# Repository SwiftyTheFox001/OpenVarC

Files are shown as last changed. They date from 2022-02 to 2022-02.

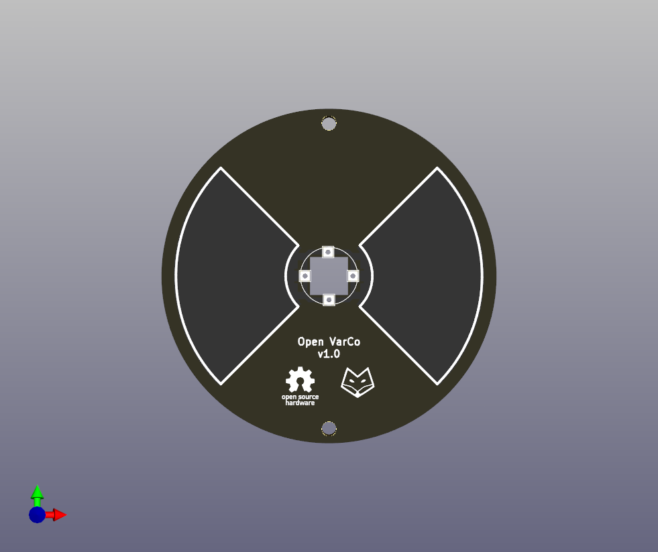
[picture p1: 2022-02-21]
Images/openVarC_large_Rotor.png

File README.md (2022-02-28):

# OpenVarC
OSHW Variable Capacitor based on PCBs

This project intends to find a viable alternative for the variable capacitors for high voltages that got rare in modern electronics, but are still in demand for ham radio operators for various projects. At the moment this project is still in "beta phase" covers only one size of cap and some specs are still to be tested like the max. AC voltage capability. Please consider this while rebuilding a capacitor.

Features:
- Modular
- Uses PCBs and easily available mechanic parts (metric screws, washers & nuts)
- at least 2kV 
- Holes for light barrier to allow automatic centering

Future development:
- different sizes
- measuring max. Voltage capability
- optimizing the center tapped 

On ordering the PCBs:
- Thickness: 0.8mm
- Amount of PCBs: use calculations.ods to calculate the approximate amount of needed stacks and order a bit more. The amount depends on the dielectric properties of the used FR4 material. Milage may vary!

What you need for the large VarCs:
- Stator plate PCBs
- Rotor plate PCBs
- 4x M4 threaded rods of the same length
- 16x M4 Nuts
- M4 Washers (4 between 2 stators)
- 8mm rectangular aluminium extrusion (Axis) Note: Can be a U-shaped extrusion as well
- Cable shoes that fit on the M4 threaded rod
- 3D printed parts:
  - 2x H750.stl
  - 1x H751_1.stl
  - 1x H751_2.stl
- a Saw 

Assembly:
1) Lengthen the rectrangular axis and the 4 threaded rods depending on your need. Calculate some extra length to ensure that you can add a few stacks later if needed
2) put one M4 Nut min. 1cm from the ends of each threaded rod
3) Stack the PCBs the following way:
- Slide stator plate with silk screen showing upside (text/markings) on the four threaded rods
- First stack: put the axis inside the circular center hole of the stator plate
- Slide rotor plate with silk screen showing upside (text/markings) on the Axis
- Slide one washer on each of the threaded rods
- repeat the process with sliding a stator plate on top and ensure that the light barrier hole is aligned with the bottom layers
4) finishing the assembly
- ensure that all outside plates are stator plates
- put 4 M4 Nuts on top of thestack and tighten them carefully
- put the 3D printed parts 751_1 and 751_2 on both ends of the axis. Move the axis so, that the part 751_2 (endcap that prevents axis from going throuh) lies flush with the stator plate
- slide the two 3D printed parts 750 on the ends of the caps. Ensure that the light barrier holes are aligned
- slide the cable shoes on the threaded rods
- tighten with with M4 nuts

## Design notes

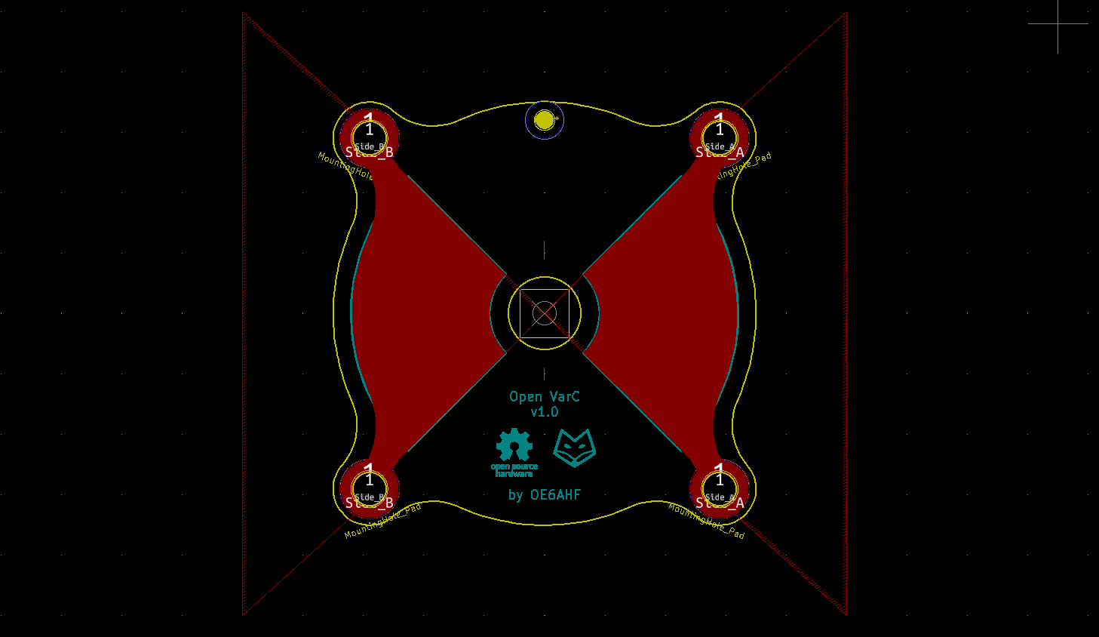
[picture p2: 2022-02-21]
Images/openVarC_large_Stator.png

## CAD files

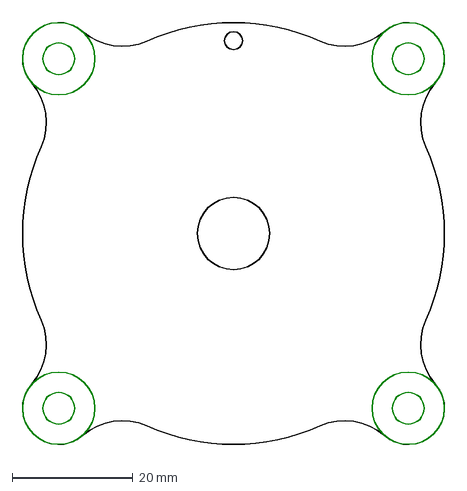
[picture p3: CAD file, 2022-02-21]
3D Files/#openVarC_large.dxf
72.1 x 72.1 mm

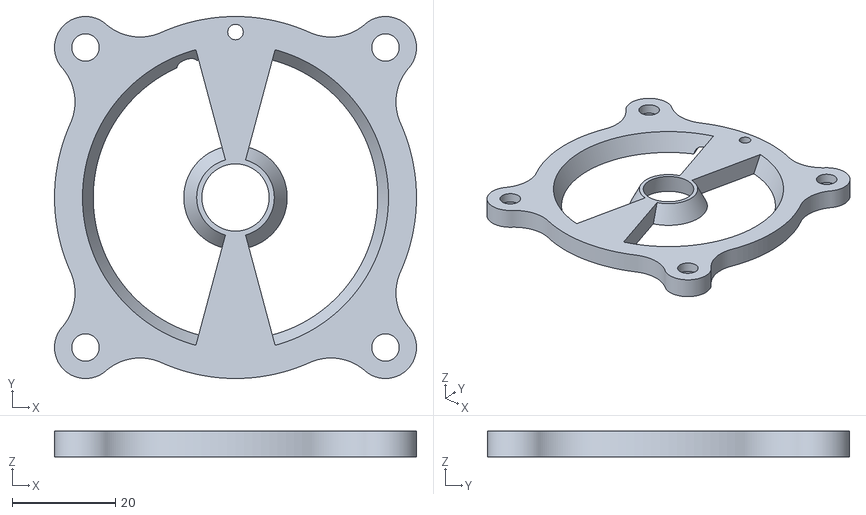
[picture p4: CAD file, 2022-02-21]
3D Files/STL/H750.stl
70.0 x 70.0 x 5.00

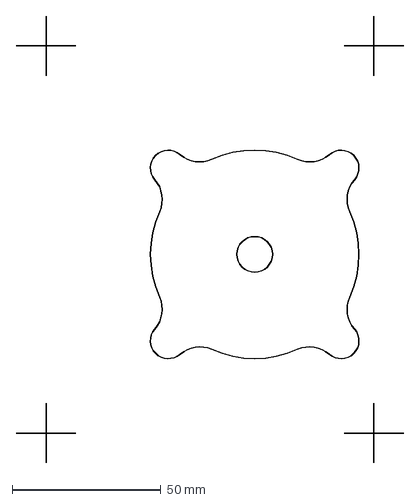
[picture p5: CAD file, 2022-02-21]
VarCo_large/openVarC_large.dxf
130.0 x 150.0 mm

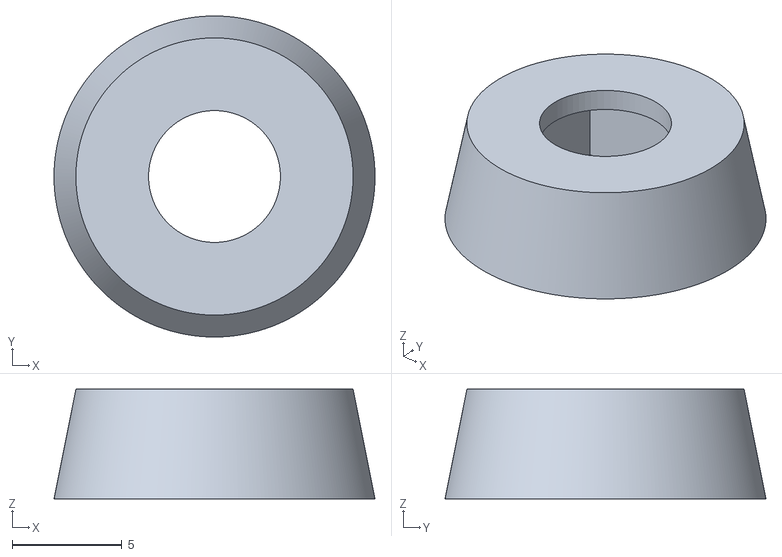
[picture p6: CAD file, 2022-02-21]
3D Files/STL/H751_2.stl
14.6 x 14.6 x 5.00

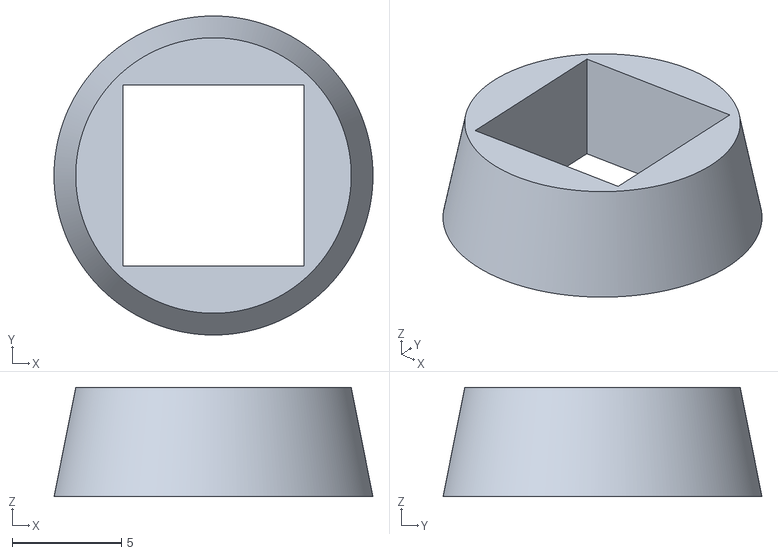
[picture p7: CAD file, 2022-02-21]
3D Files/STL/H751_1.stl
14.6 x 14.6 x 5.00

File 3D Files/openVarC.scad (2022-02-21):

//OpenVarc - 3D Files and Assembly
//
//by OE6AHF & OE6MDW
//relesed under the CC-BY-SA 4.0

use_stls = true;
LOD=128;

include <openVarC_parts.scad>



//
// Printable PARTS
//

*H750();		//Top Plate
*H751_1();		//Alignment Disk Open
*H751_2();		//Alignment Disk Endcap

//
// ASSEMBLY
//

assembly();

	
module assembly()
    {
    translate([0,0,5+0+6+pcbStacks*(2*pcbHeight+2*pcbSpace)+pcbHeight])
        {
        H750(); // Top Plate
        H751_2(); // Alignment Disk       
        }
    translate([0,0,11])
		rotate([0,180,0])
        {
        H750(); // Top Plate
        H751_1(); // Alignment Disk       
        }
              
    // VarCo
	translate([0,0,5+0+6])
		P100();
	
    }
    
//
//  PARTS
//

//
// H750 - Top Plate
//

module H750()
    {
    if (use_stls)
        {
        color("orange")
            import("./STL/H750.stl");
        }
    else
        {
        color("darkorange")
        difference()
            {
            union()
                {
                    
                // Outer Ring
                difference()
                    {
                    union()
                        {
                        linear_extrude(height=5)
                            import($fn=128, "openVarC_large.dxf", "Stator");
                        }
                    translate([0,0,-0.01])
                        cylinder($fn=LOD*2, r2=60/2, r1=55/2, h=6);
                    
                    for (i=[0:3])
                        {
                        rotate([0,0,90*i])
                            translate([29,29,-0.5])
                            cylinder($fn=64, r=9.1/2, h=3.05);
                        }
                        
                    }
                //Inner Ring
                translate([0,0,0])
                    cylinder($fn=LOD*2, r2=15/2, r1=20/2, h=5);               
                
                //Bars
                linear_extrude(height=5)
                    polygon(points=[
                        [31*cos(75),31*sin(75)],
                        [31*cos(105),31*sin(105)],

                        [5*cos(105),5*sin(105)],
                        [5*cos(-105),5*sin(-105)],

                        [31*cos(-105),31*sin(-105)],
                        [31*cos(-75),31*sin(-75)],       
       
                        [5*cos(-75),5*sin(-75)],
                        [5*cos(75),5*sin(75)],                    
                        ]);
                    
                }
            translate([0,0,-0.01])
                cylinder($fn=LOD*2, r1=15/2, r2=13/2, h=5.02);          
                         
            rotate([0,0,20])
                translate([0,25,0])
                rotate([-90,0,0])
                cylinder($fn=32,r=2, h=50);
                
                

            }
        }        
    }

//
// H751 - Alignment Disk
//

module H751_1()
    {
    a=0.2;
    if (use_stls)
        {
        color("orange")
            import("./STL/H751_1.stl");
        }
    else
        {
        color("orange")
        difference()
            {
            union()
                {
                    
                // Outer Ring
                translate([0,0,-0.0])
                intersection()
                    {
                    translate([0,0,-0.01])
                        cylinder($fn=LOD*2, r1=15/2-a, r2=13/2-a, h=5.02);
                    translate([0,0,0.0])
                        cylinder(r=16/2,h=5);
                        
                    }
                }
            translate([-8.3/2,-8.3/2,-1])
                cube([8.3,8.3,10-0.0]);
            translate([0,0,-0.5])    
            cylinder($fn=64, r=3, h=8);

            }
        }        
    }

module H751_2()
    {
    a=0.2;
    if (use_stls)
        {
        color("orange")
            import("./STL/H751_2.stl");
        }
    else
        {
        color("orange")
        difference()
            {
            union()
                {
                    
                // Outer Ring
                translate([0,0,-0.0])
                intersection()
                    {
                    translate([0,0,-0.01])
                        cylinder($fn=LOD*2, r1=15/2-a, r2=13/2-a, h=5.02);
                    translate([0,0,0.0])
                        cylinder(r=16/2,h=5);
                        
                    }
                }
            translate([-8.3/2,-8.3/2,-1])
                cube([8.3,8.3,10-5.0]);
            translate([0,0,-0.5])    
            cylinder($fn=64, r=3, h=8);

            }
        }        
    }
        
module mirror_copy(vector)
        {
        children();
        mirror(vector) children();    
            
        }	

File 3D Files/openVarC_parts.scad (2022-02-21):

//OpenVarc - Hardware Parts
//
//by OE6AHF & OE6MDW
//relesed under the CC-BY-SA 4.0



// Screws
*H103_1(); 			// M3 Screw Lenth 6mm Din 912
*H103_20(); 		// M3 Screw Lenth 20mm Din 912

// Nuts
*H203();			// H203-1 M3 Nut DIN 934
*H206();			// H206-1 M6 Nut DIN 934

// Washers
*H306();			// H206-1 M6 Washer DIN 125


// Shafts / Axis / Cams
*H500_1();			//H500_1 M6_Gear_Shaft
*H510_1();			//8x8mm Hollow Aluminium Extrusion


// Phantoms
*P100();			// Varco Preassembled

*P0001_DIN912(); 	// Cylinder head screw
*P0002_DIN125(); 	// Washer
*P0003_DIN934();	// Nut


// Varco Parameters

pcbHeight = 0.8;
pcbSpace = 0.2;
pcbStacks = 34;


//
// H103-6 M3 Screw Lenth 6mm Din 912
//

module H103_1()
	{
	P0001_DIN912(d=3, l=6, k=3, dk=5.68, s=2.5, t=1.9);
	}


//
// H103-20 M3 Screw Lenth 20mm Din 912
//

module H103_20()
	{
	P0001_DIN912(d=3, l=20, k=3, dk=5.68, s=2.5, t=1.9);
	}


//
// H2032-2 M3 Nut Din 934
//

module H203()
	{
	P0003_DIN934(d=3, m=2.4, e=6.01);
	}


//
// H2032-2 M5 Nut Din 934
//

module H206()
	{
	P0003_DIN934(d=5, m=4, e=8.79);
	}


//
// H206 M5 Washer Din 934
//

module H306()
	{
	P0002_DIN125(d=5.3, d1=10, h=1);
	}

//
//H500_1 M5_Gear_Shaft
//
	
module H500_1()
    {
    color("silver")
    	cylinder($fn=24, r=5/2, h=100);
    }


//8x8mm Hollow Aluminium Extrusion
module H510_1()
	{
	axis_height=pcbStacks*(2*pcbHeight+2*pcbSpace)+pcbHeight+19;
	
	color("grey")
	difference()
		{
		translate([-4,-4,-15])
			cube([8,8,axis_height]);
		translate([-3,-3,-15.1])
			cube([6,6,axis_height+0.2]);			
		}
	}



//VarCo_Stator
module E100_1()
	{
	linear_extrude(height=pcbHeight)
		import($fn=128, "openVarC_large.dxf", "Stator");
	}

//VarCo_Rotor
module E100_2()
	{
	linear_extrude(height=pcbHeight)
		import($fn=128, "openVarC_large.dxf", "Rotor");	
	}


//VarCo Assembled
module P100()
	{
	mirror([0,0,0])
		{
		for (i=[0:pcbStacks-1])
			{
			color("green")
			translate([0,0,i*(2*pcbHeight+2*pcbSpace)])
				E100_1();
				color("lightgreen")
			translate([0,0,(1*pcbHeight+1*pcbSpace)+i*(2*pcbHeight+2*pcbSpace)])
				E100_2();
			}
		color("green")
		translate([0,0,pcbStacks*(2*pcbHeight+2*pcbSpace)])
			E100_1();
		
		//Center Axis
		H510_1();
		
		//Gear Shafts & Nuts
		for (i=[0:3])
			rotate([0,0,i*90])
				{
				translate([29,29,-20])
					H500_1(); //M5 Gear shaft
					
			//Top Nuts	
				translate([29,29,pcbStacks*(2*pcbHeight+2*pcbSpace)+pcbHeight])
					H206();
				translate([29,29,pcbStacks*(2*pcbHeight+2*pcbSpace)+pcbHeight+5])
					H206();
			//Bottom Nuts			
				translate([29,29,-4])
					H206();
				translate([29,29,-9])
					H206();
					
				}
		}	
	}
	
//
// PANTOM MODULES
//
	
module P0001_DIN912(d=1.4, l=10, k=1.4, dk=2.6, s=1.3, t=0.6)
	{
	color("lightgrey")
	translate([0,0,-k])
	difference()
		{
		union()
			{
			cylinder($fn=32, r=dk/2, h=k);
			translate([0,0,0.1])
				cylinder($fn=32, r=d/2, h=k+l-0.1);
			}
		translate([0,0,-0.1])
			cylinder($fn=6, r=s*2/sqrt(3)/2, h=t+0.1);
		}
	}

module P0002_DIN125(d=2.2, d1=5, h=0.3)
	{
	color("lightgrey")
	difference()
		{
		union()
			{
			cylinder($fn=32, r=d1/2, h=h);
			}
		translate([0,0,-0.1])
			cylinder($fn=32, r=d/2, h=h+0.2);
		}
	}

module P0003_DIN934(d=1, m=0.8, e=2.71)
	{
	color("lightgrey")
	difference()
		{
		union()
			{
			cylinder($fn=6, r=e/2, h=m);
			}
		translate([0,0,-0.1])
			cylinder($fn=32, r=d/2, h=m+0.2);
		}
	}	
	
//
// PRIMITITVE FUNCTIONS	
//
	
module copy_rotate(rot=[0,0,90], times=1) 
{ 
    children(); 
    for (i=[1:times])
        rotate(rot*i) children(); 
}
    
module copy_mirror(vec=[0,1,0])
{ 
    children(); 
    mirror(vec) children(); 
}		

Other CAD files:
3D Files/openVarC_large.dxf

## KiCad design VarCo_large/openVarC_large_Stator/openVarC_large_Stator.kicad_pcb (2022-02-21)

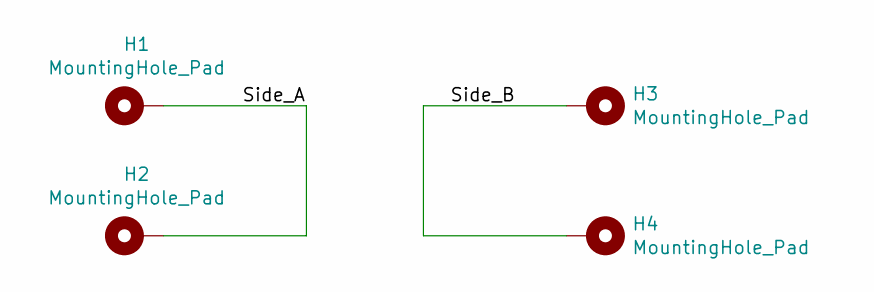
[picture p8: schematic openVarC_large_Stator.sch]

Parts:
H1, H2, H3, H4: MountingHole_Pad; MountingHole_5.3mm_M5_ISO7380_Pad_TopBottom

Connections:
/Side_A: H1.1, H2.1
/Side_B: H3.1, H4.1

Board: 2 copper layers, 4 parts (0 on the bottom side), 2 nets, no tracks yet.

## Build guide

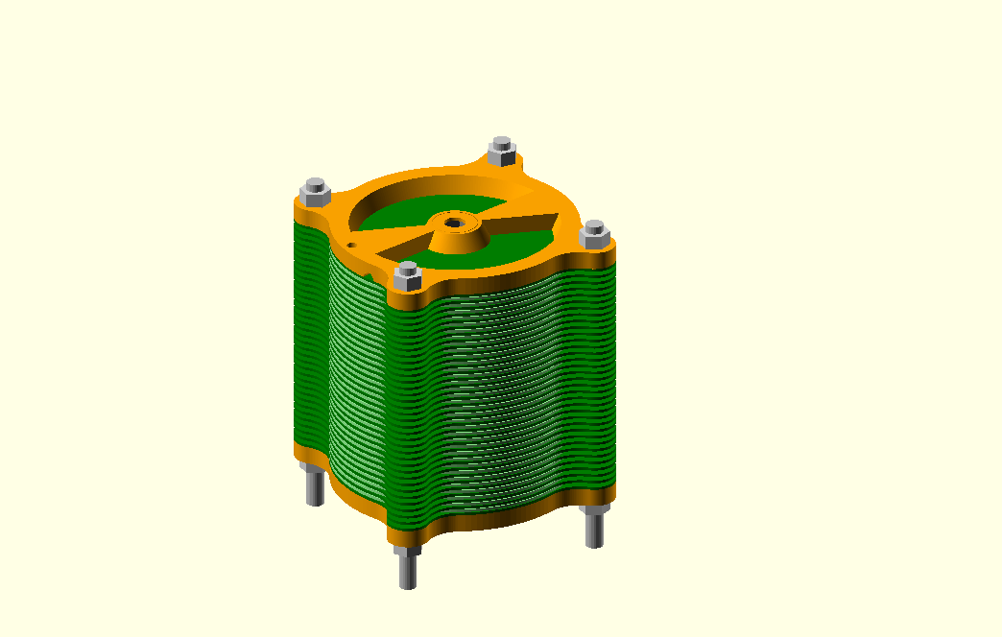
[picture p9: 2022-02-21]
Images/openVarC_assembled.png

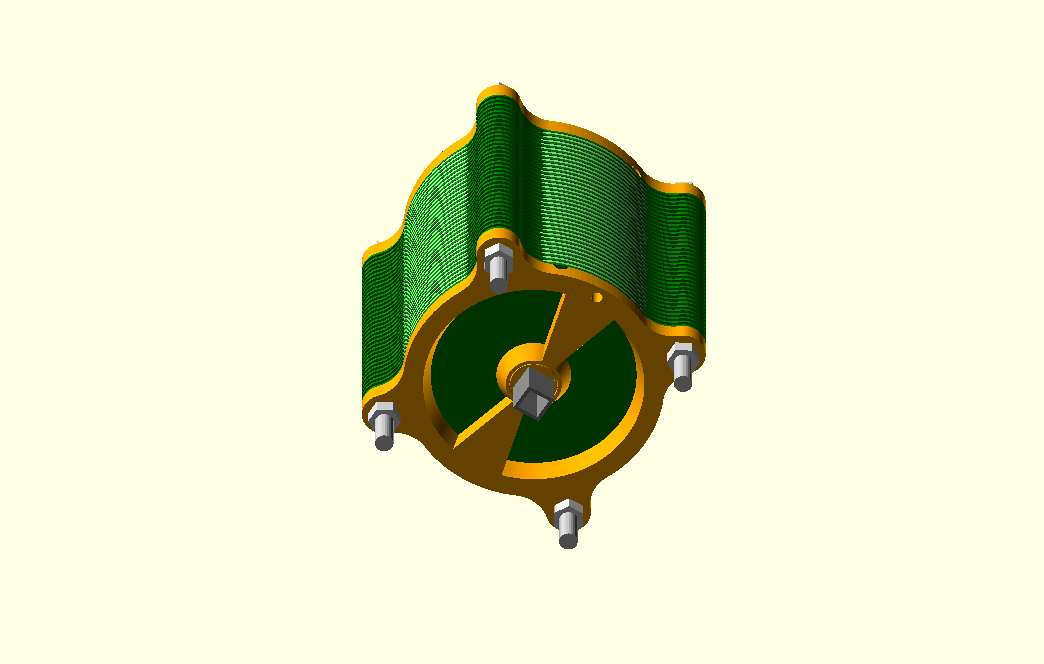
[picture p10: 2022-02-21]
Images/openVarC_assembled_bottom.png

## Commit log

2022-02-21 First Release
    [Calculations.ods, openVarC_large.dxf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]
2022-02-21 Added 3D Files
    [#openVarC_large.dxf, H750.stl, H751_1.stl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]
